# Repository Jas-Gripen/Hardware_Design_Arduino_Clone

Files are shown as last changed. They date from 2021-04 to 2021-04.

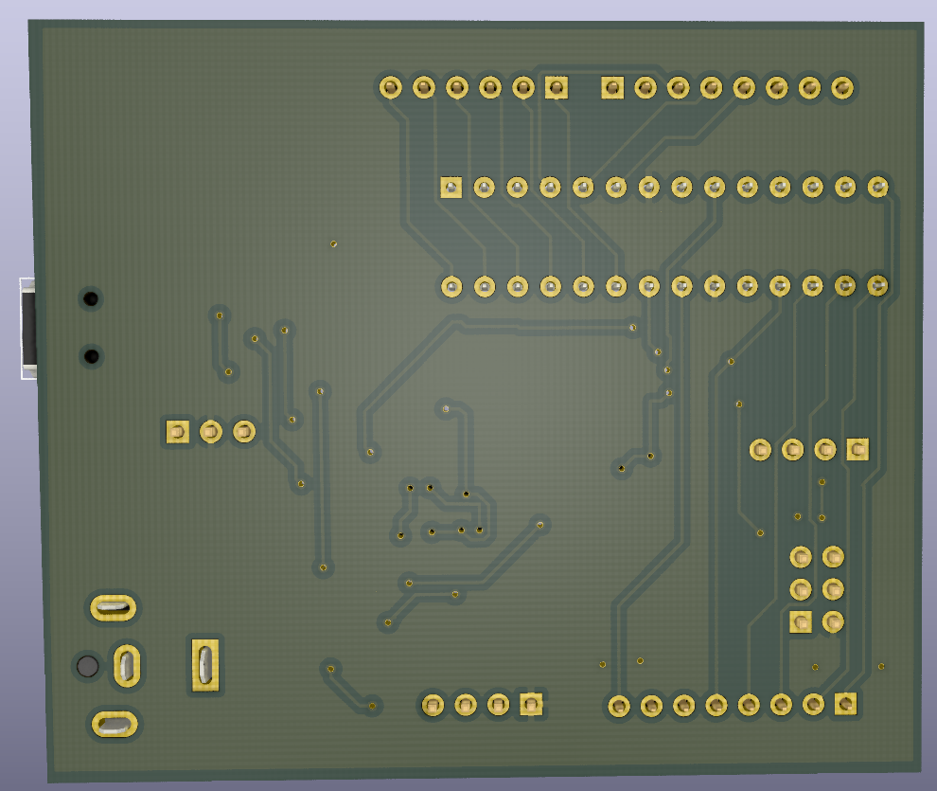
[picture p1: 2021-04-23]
Pictures/3D_image_of_board_bottom_view.png

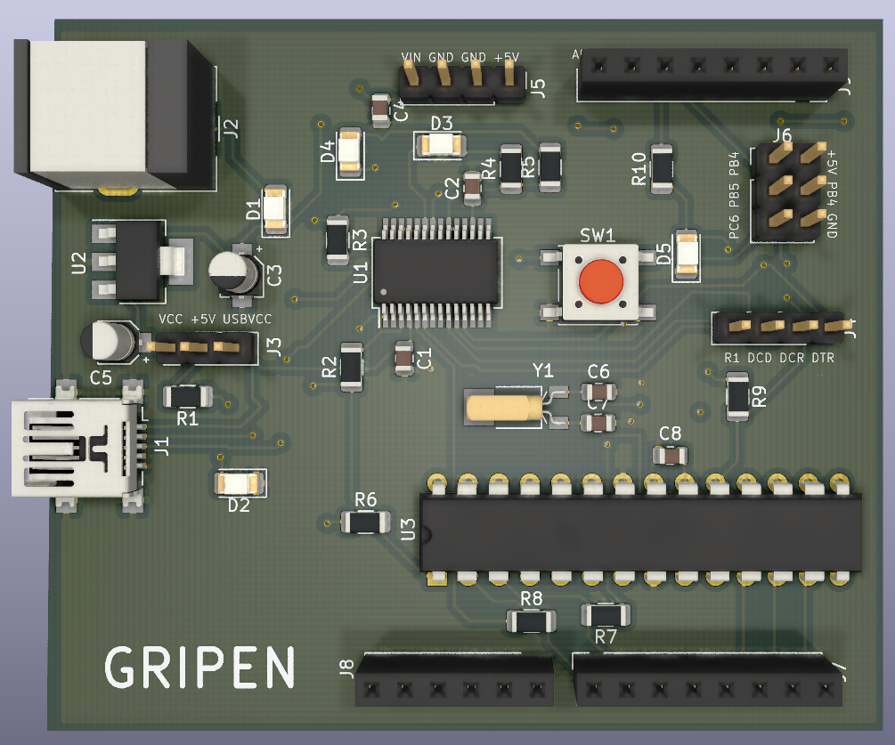
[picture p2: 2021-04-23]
Pictures/3D_image_of_board_top_view.png

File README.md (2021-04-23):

# Hardware_Design_Arduino_Clone
I made schematics for an Arduino Clone in KiCad.
There is a description of why I chosed to design the board like I did in the PCB_Report.pdf file.

The original schematic (only Eeschema type) are avalible here: https://www.arduino.cc/en/uploads/Main/arduino_NG_schematic.png
The placement of the components as well as the version of them are of my own choosing. The same goas for the PCB-traces and vias.

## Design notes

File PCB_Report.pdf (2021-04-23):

## PCB Report

Abstract

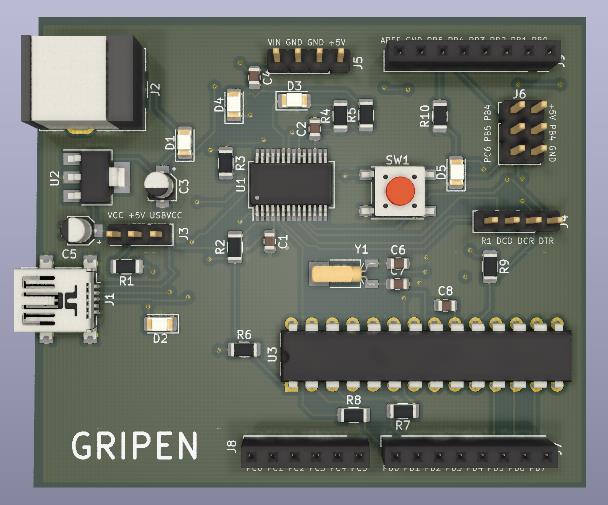
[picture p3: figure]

3D visualization of a pcb-design(Arduino clone), Pcbnew, KiCad, Daniel Gripenstedt

This document contains a description of a PCB design. The report should clarify why the circuit board looks the way it does and the thoughts behind the different design choices. There are also pictures of various drawings and 3D visualization of the circuit board.

### Overview

The circuit board is an Arduino clone (Arduino Nuova Generazione (NG) v4.0) which has an 8-bit MCU (ATmega8-16PU [1] and an FT232RL (USB-UART interface) [2]. Program code is sent over with a USB mini-B cable, which can also act as a power supply. There are several LEDs and a reset button. A crystal of 16MHz is placed on the card. All drawings are created with KiCad [3].

### Components

Most components are of type SMD as these are cheaper than THT. Contact pins and power supply are of type THT. In total, there are 37 components where the smallest are 0805. Smaller components were not considered necessary as there was sufficient space on the card. All components are located on the top of the card.

### Microcontroller

The microcontroller used is an ATmega8-16PU. This MCU has 8Kbytes of On-Chip In-System Reprogrammable Flash memory. Program code is sent over with a USB mini-B cable using the MCU's Boot Loader-Support [1].

### Power and power supply

The MCU requires 4.5V – 5.5V voltage [1]. Two polarized capacitors with 100uF have been placed by the cards power supply as they may have a higher capacitance at a lower price than those that are not polarized.

Voltage can be supplied directly with 5V from USB mini-B or via a voltage divider and the card's "power jack" but it is also possible to connect an external power source via the VIN stick connected before the voltage divider. Several decoupling capacitors have been used to protect the circuits from current spikes.

Power options:

1. USB mini-B cable connected to, for example, a computer.
2. Power Jack with, for example, an AC to DC converter.
3. VIN stick with, for example, a 9V battery.

### PCB Layout

This design is of a two-layer card with a ground plane and a voltage plane. The crystal Y1 is located near the MCU and the loading capacitance have been placed close to the crystal. This is good because it is a sensitive circuit. The load capacitances are positioned so that their fields are counterproductive and the signals from the crystal travels close to each other so that the magnetic fields cancel each other out. No other wires have been pulled parallel or above which may interfere. The ground signal from the crystal to the MCU is short and close to the other two signals, which gives a small loop area. The ground plane got disconnected by the crystal but was solved by connecting a bridge between the connected and disconnected ground planes.

Decoupling capacitors are located near the circuits they decouple to minimize impedance and maximize decoupling efficiency.

Wires and ground/voltage planes are located a bit in from the edge of the card to prevent interference (the card may otherwise act as a patch antenna).

The circuit is partitioned so that power/voltage supply is placed on one part of the card, the MCU with resistors, crystal and capacitors on another and the FT232RL with resistors, diodes and capacitors on another part of the card.

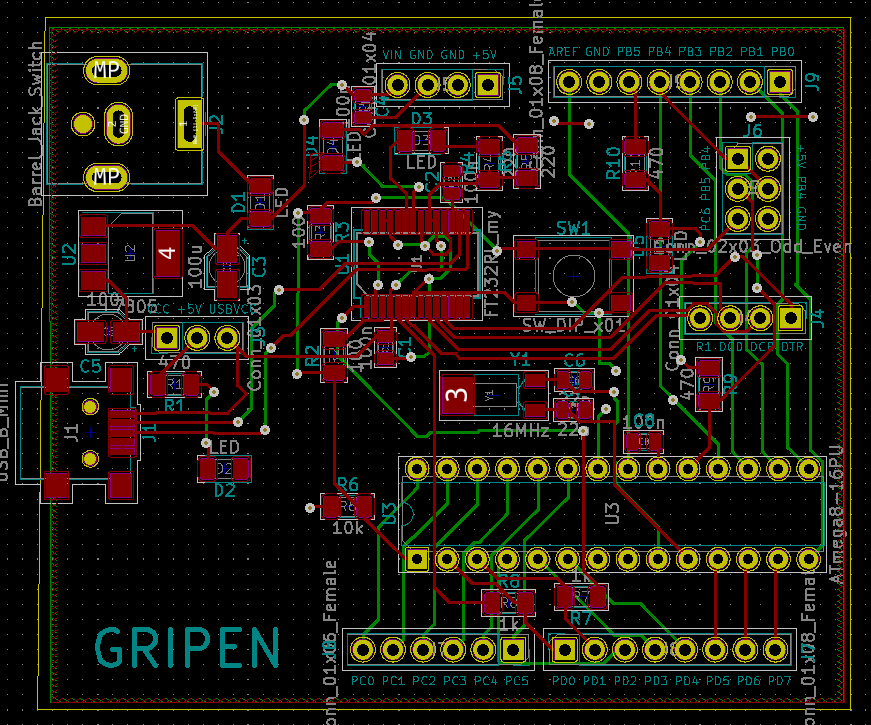
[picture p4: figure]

Front of the circuitboard, Pcbnew, KiCad, Daniel Gripenstedt

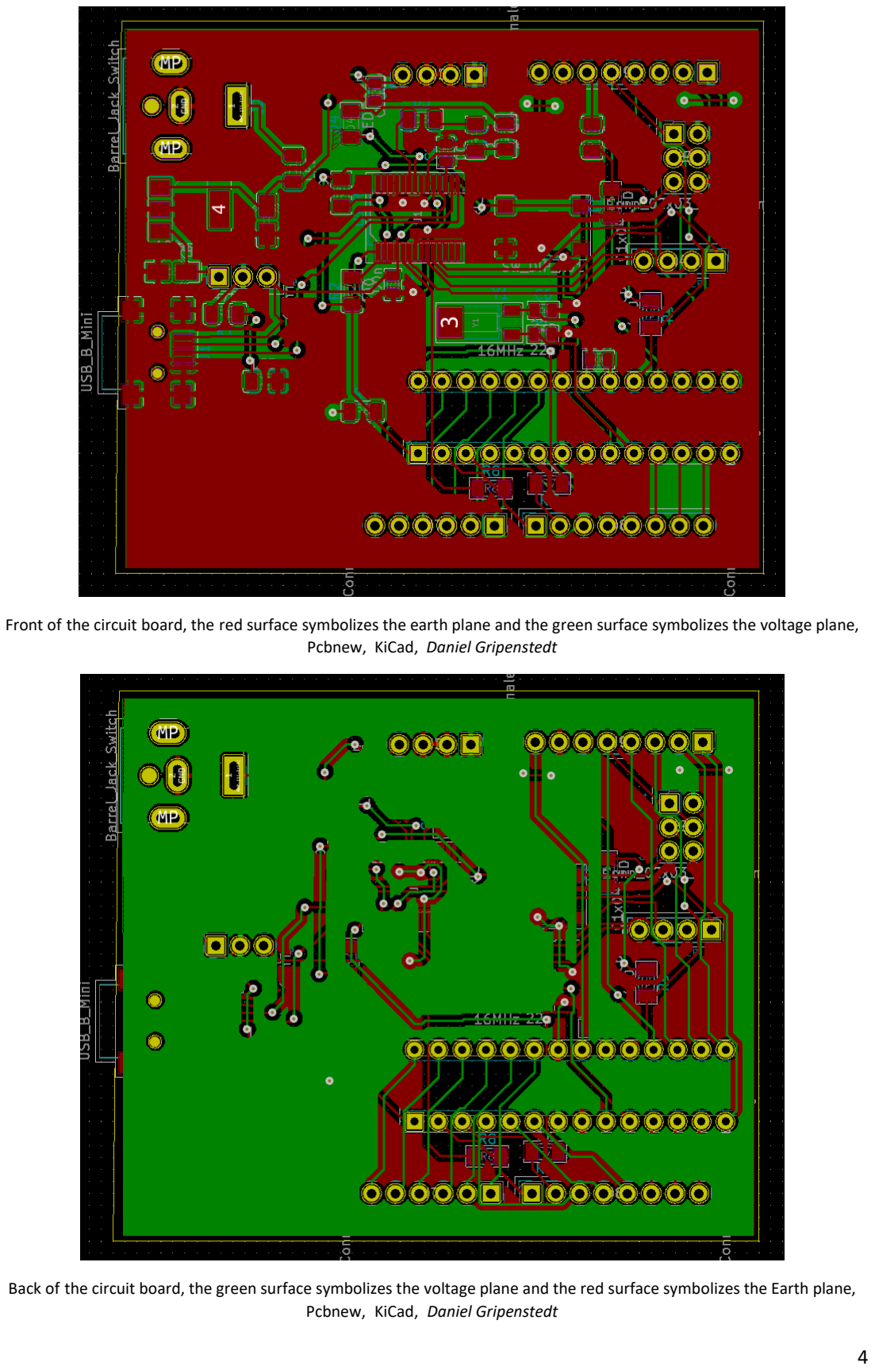
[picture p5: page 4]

Front of the circuit board, the red surface symbolizes the earth plane and the green surface symbolizes the voltage plane, Pcbnew, KiCad, Daniel Gripenstedt

Back of the circuit board, the green surface symbolizes the voltage plane and the red surface symbolizes the Earth plane, Pcbnew, KiCad, Daniel Gripenstedt

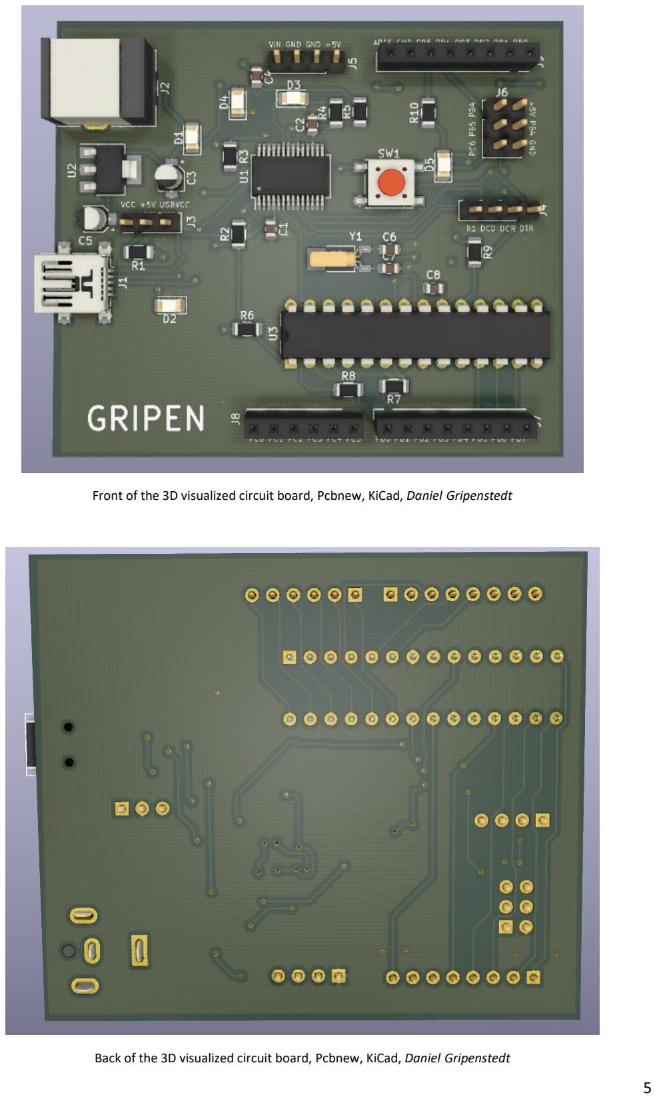
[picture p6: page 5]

Front of the 3D visualized circuit board, Pcbnew, KiCad, Daniel Gripenstedt

Back of the 3D visualized circuit board, Pcbnew, KiCad, Daniel Gripenstedt

### Drawing

The first image is on the entire drawing, the three lower slides are parts of the drawing but on a larger scale.

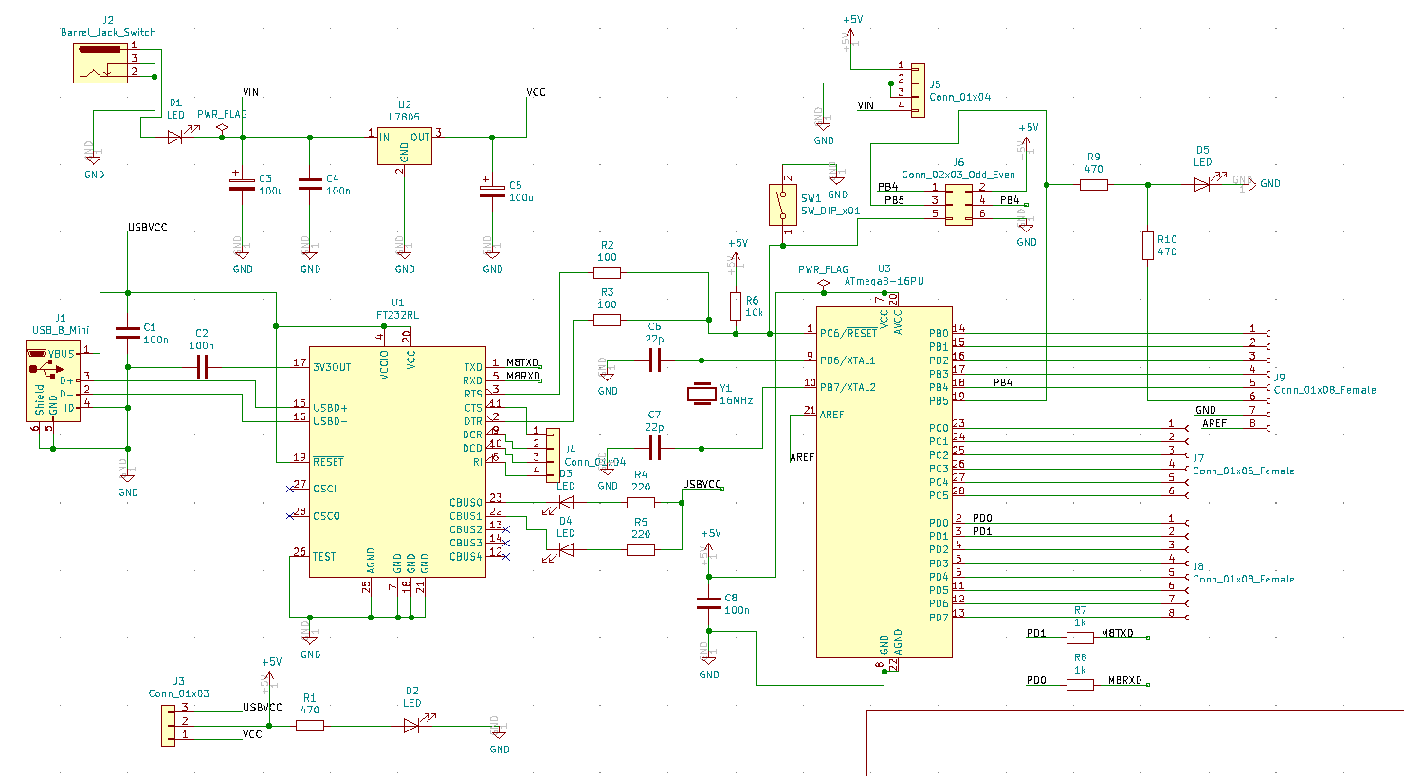
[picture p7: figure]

Drawing in Easchema, KiCad, Daniel Gripenstedt

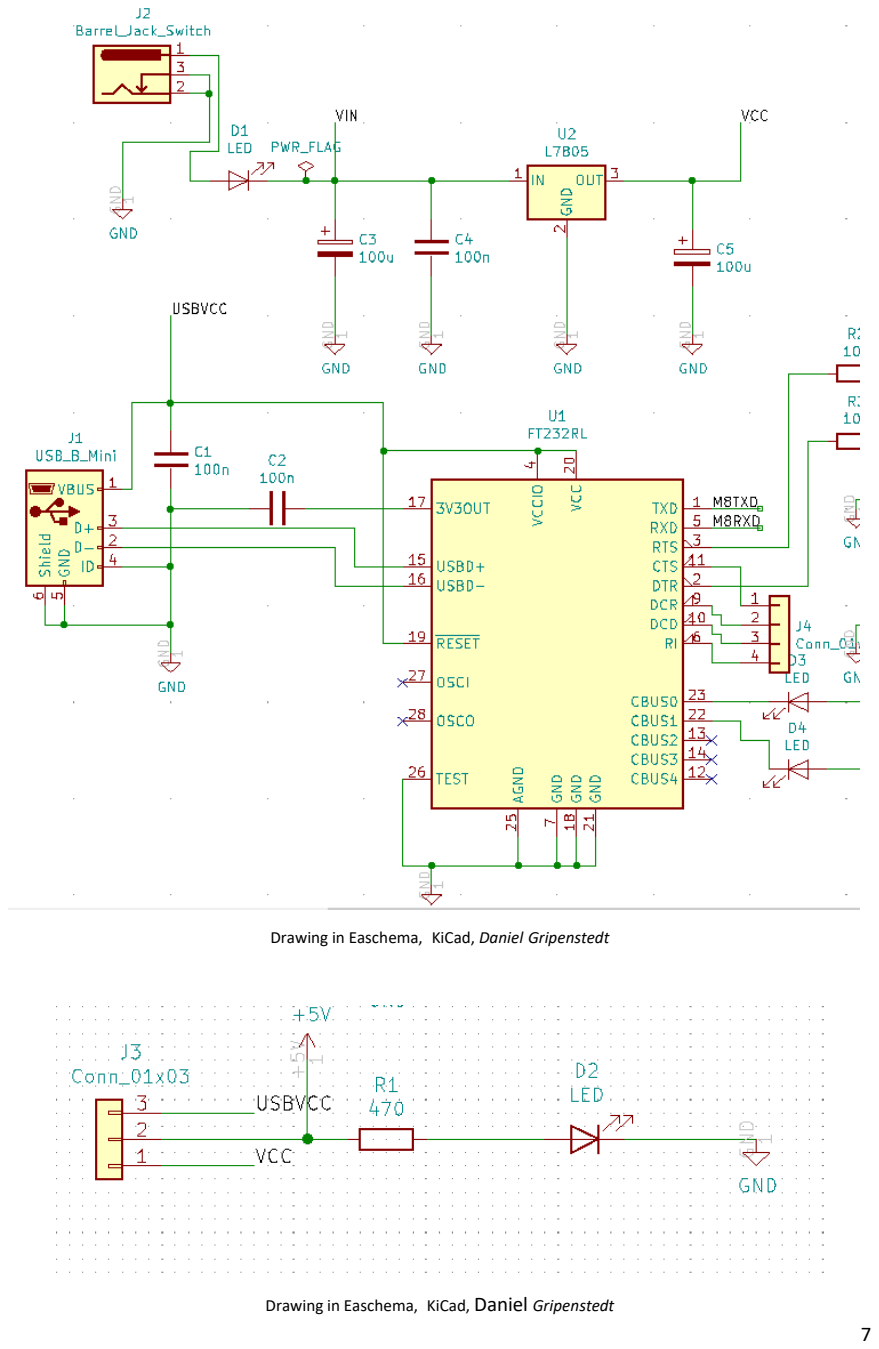
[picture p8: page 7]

Drawing in Easchema, KiCad, Daniel Gripenstedt

Drawing in Easchema, KiCad, Daniel Gripenstedt

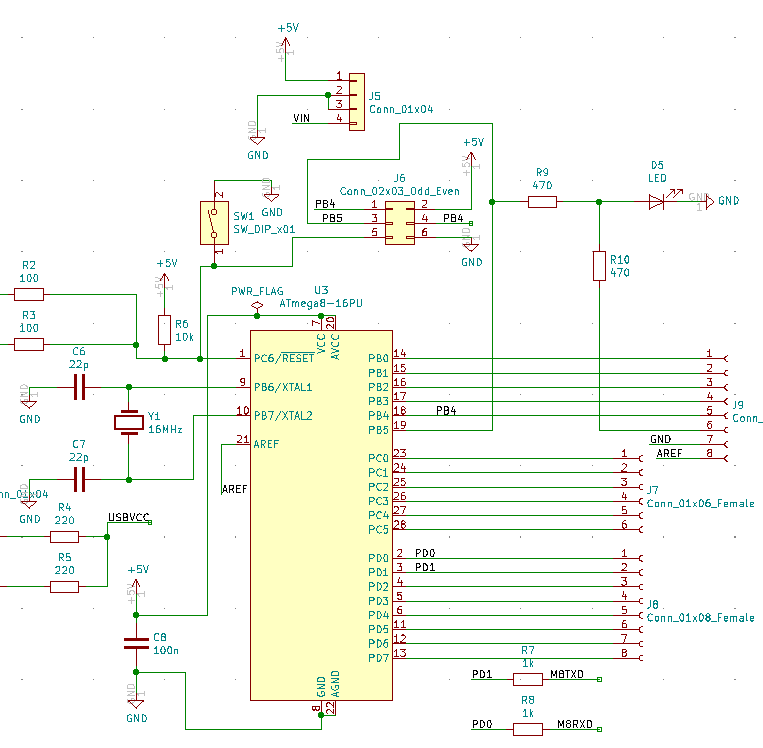
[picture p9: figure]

Drawing in Easchema, KiCad, Daniel Gripenstedt

### Bom List

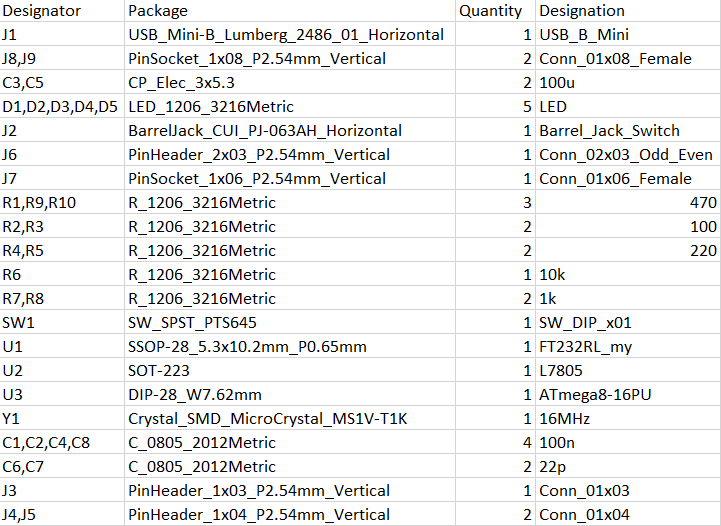
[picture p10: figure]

BOM list generated by Pcbnew, KiCad, Daniel Gripenstedt

### References

[1] (2020), ATmega8/L datasheet - ATMEGA8-16PU-Microchip datasheet-14702621.pdf, Available: https://datasheet.octopart.com/ATMEGA8-16PU-Microchip-datasheet-14702621.pdf
[2] (2020), FT232R - DS_FT232R.pdf, Available: https://www.ftdichip.com/Support/Documents/DataSheets/ICs/DS_FT232R.pdf
[3] (2020), KiCad EDA, A Cross Platform and Open Source Electronics Design Automation Suite, Available: https://kicad-pcb.org/

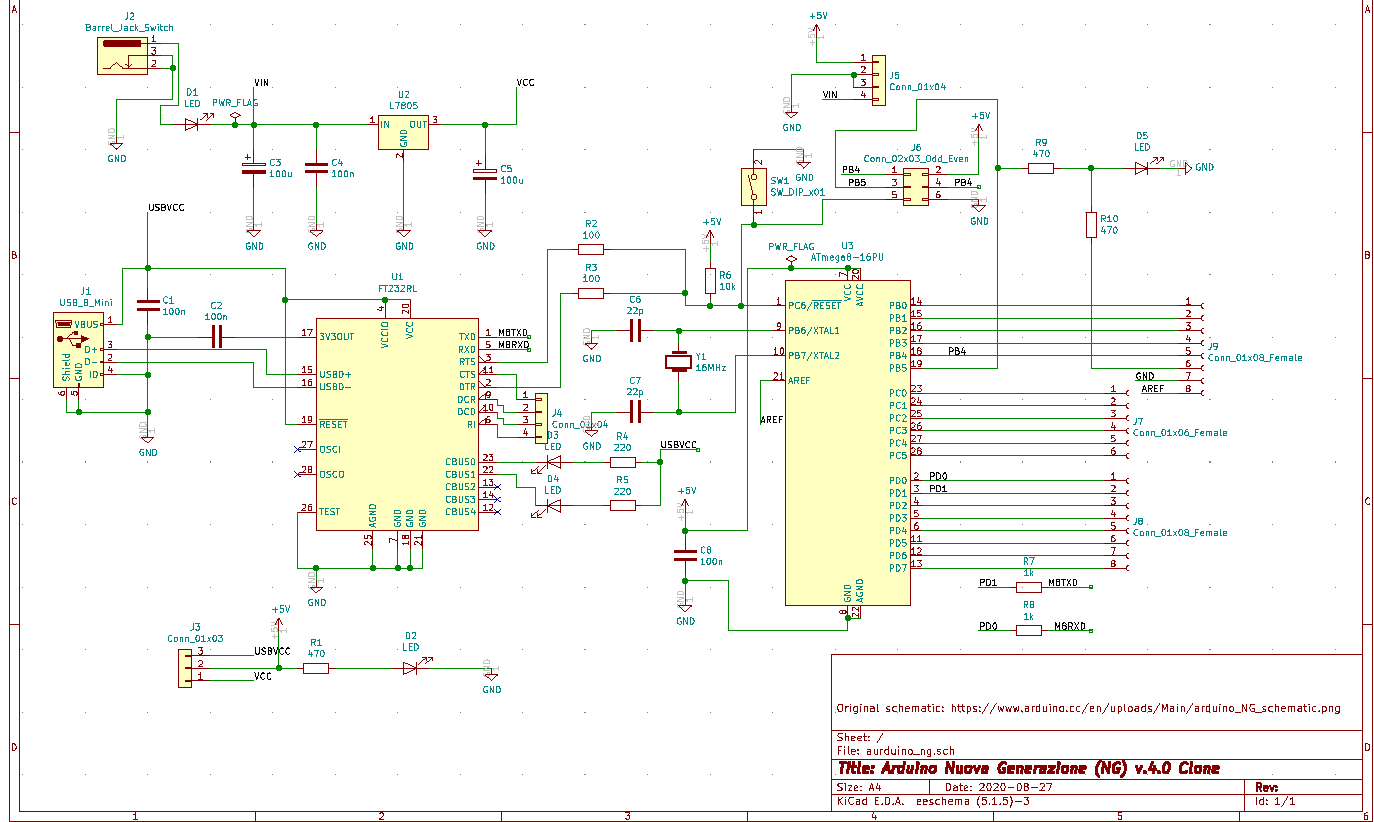
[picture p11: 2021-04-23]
Pictures/Eeschema.png

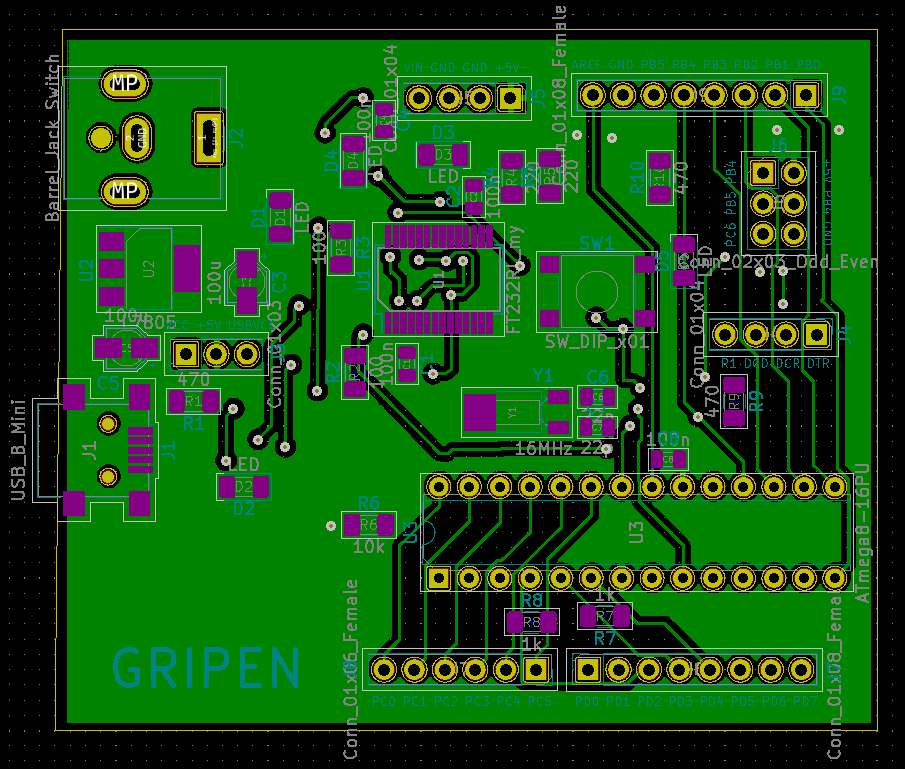
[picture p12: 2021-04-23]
Pictures/Pcbnew_bottom_plane.png

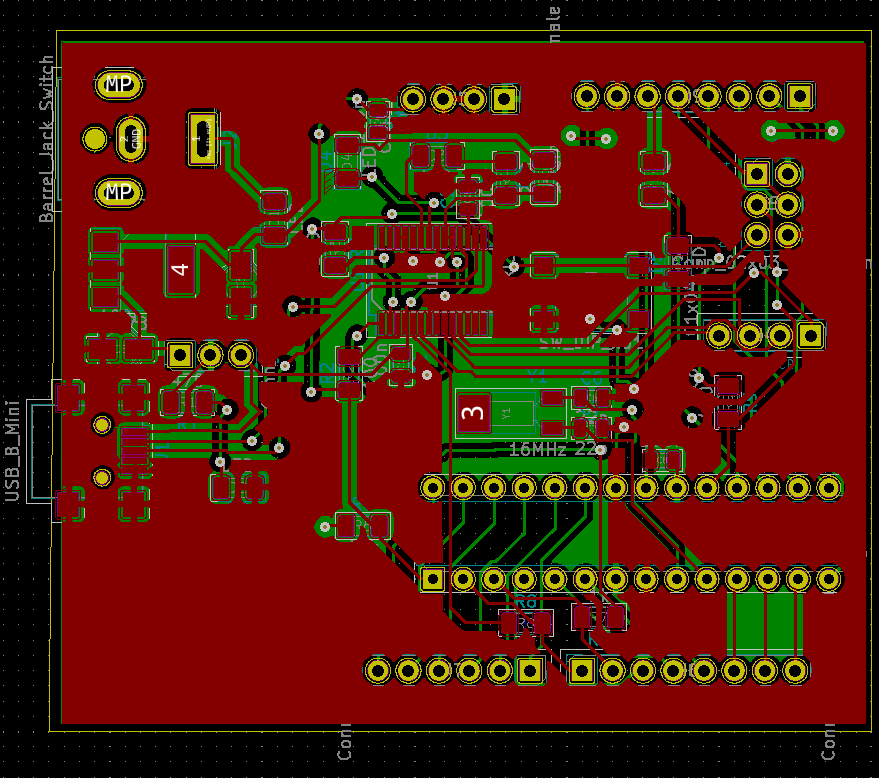
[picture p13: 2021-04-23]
Pictures/Pcbnew_top_plane.png

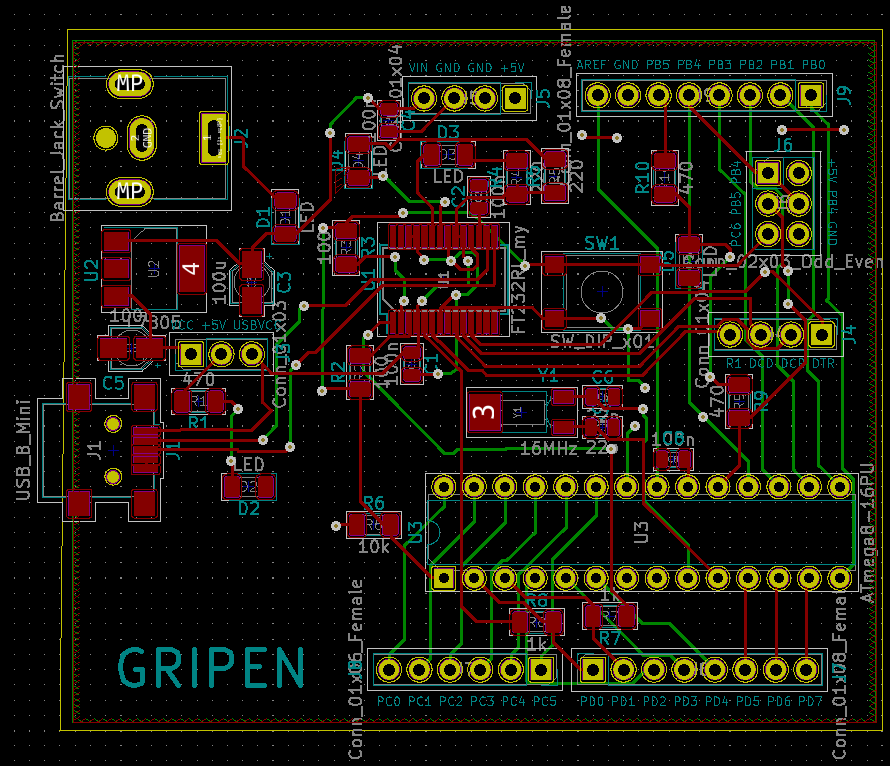
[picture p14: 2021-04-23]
Pictures/Pcbnew.png

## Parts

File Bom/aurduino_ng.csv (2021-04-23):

Id | Designator | Package | Quantity | Designation | Supplier and ref
1 | J1 | USB_Mini-B_Lumberg_2486_01_Horizontal | 1 | USB_B_Mini
2 | J8,J9 | PinSocket_1x08_P2.54mm_Vertical | 2 | Conn_01x08_Female
3 | C3,C5 | CP_Elec_3x5.3 | 2 | 100u
4 | D1,D2,D3,D4,D5 | LED_1206_3216Metric | 5 | LED
5 | J2 | BarrelJack_CUI_PJ-063AH_Horizontal | 1 | Barrel_Jack_Switch
6 | J6 | PinHeader_2x03_P2.54mm_Vertical | 1 | Conn_02x03_Odd_Even
7 | J7 | PinSocket_1x06_P2.54mm_Vertical | 1 | Conn_01x06_Female
8 | R1,R9,R10 | R_1206_3216Metric | 3 | 470
9 | R2,R3 | R_1206_3216Metric | 2 | 100
10 | R4,R5 | R_1206_3216Metric | 2 | 220
11 | R6 | R_1206_3216Metric | 1 | 10k
12 | R7,R8 | R_1206_3216Metric | 2 | 1k
13 | SW1 | SW_SPST_PTS645 | 1 | SW_DIP_x01
14 | U1 | SSOP-28_5.3x10.2mm_P0.65mm | 1 | FT232RL_my
15 | U2 | SOT-223 | 1 | L7805
16 | U3 | DIP-28_W7.62mm | 1 | ATmega8-16PU
17 | Y1 | Crystal_SMD_MicroCrystal_MS1V-T1K | 1 | 16MHz
18 | C1,C2,C4,C8 | C_0805_2012Metric | 4 | 100n
19 | C6,C7 | C_0805_2012Metric | 2 | 22p
20 | J3 | PinHeader_1x03_P2.54mm_Vertical | 1 | Conn_01x03
21 | J4,J5 | PinHeader_1x04_P2.54mm_Vertical | 2 | Conn_01x04

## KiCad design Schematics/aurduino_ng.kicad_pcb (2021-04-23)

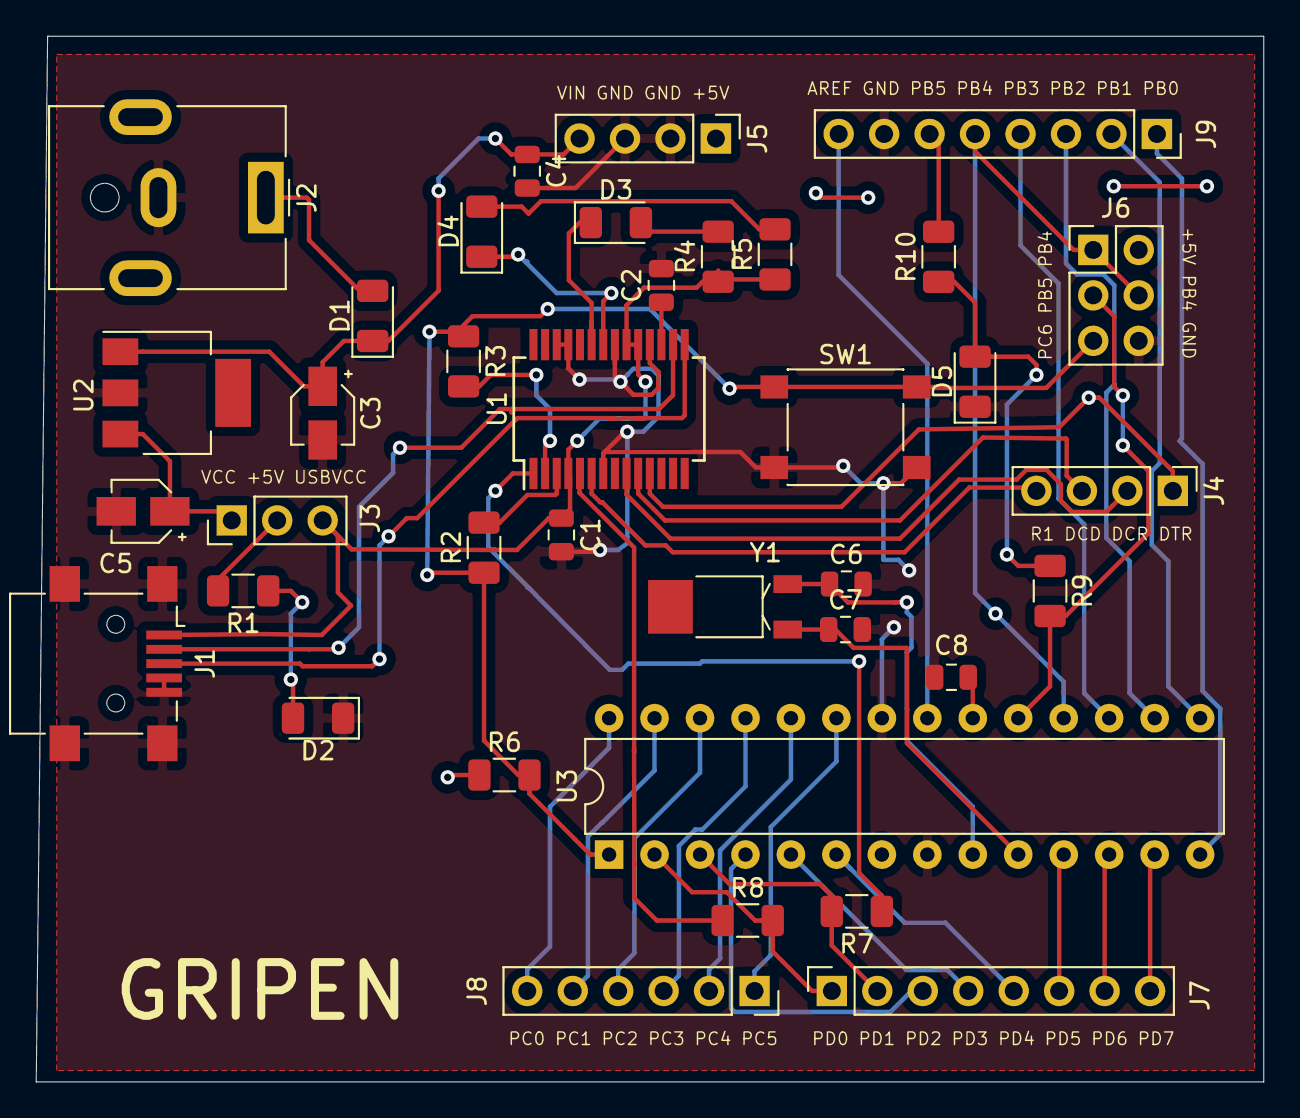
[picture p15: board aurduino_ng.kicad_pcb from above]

Board: 2 copper layers, 68.6 x 58.4 mm, 37 parts (0 on the bottom side), 48 nets.

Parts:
C1, C2, C4, C8: 100n; C_0805_2012Metric
C3, C5: 100u; CP_Elec_3x5.3
C6, C7: 22p; C_0805_2012Metric
D1, D2, D3, D4, D5: LED; LED_1206_3216Metric
J1: USB_B_Mini; USB_Mini-B_Lumberg_2486_01_Horizontal
J2: Barrel_Jack_Switch; BarrelJack_CUI_PJ-063AH_Horizontal
J3: Conn_01x03; PinHeader_1x03_P2.54mm_Vertical
J4, J5: Conn_01x04; PinHeader_1x04_P2.54mm_Vertical
J6: Conn_02x03_Odd_Even; PinHeader_2x03_P2.54mm_Vertical
J7: Conn_01x06_Female; PinSocket_1x06_P2.54mm_Vertical
J8, J9: Conn_01x08_Female; PinSocket_1x08_P2.54mm_Vertical
R1, R9, R10: 470; R_1206_3216Metric
R2, R3: 100; R_1206_3216Metric
R4, R5: 220; R_1206_3216Metric
R6: 10k; R_1206_3216Metric
R7, R8: 1k; R_1206_3216Metric
SW1: SW_DIP_x01; SW_SPST_PTS645
U1: FT232RL_my; SSOP-28_5.3x10.2mm_P0.65mm
U2: L7805; SOT-223
U3: ATmega8-16PU; DIP-28_W7.62mm
Y1: 16MHz; Crystal_SMD_MicroCrystal_MS1V-T1K

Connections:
+5V: C8.1, J3.2, J5.1, J6.2, R1.2, R6.1, U3.7, U3.20
/AREF: J9.8, U3.21
/M8RXD: R8.1, U1.5
/M8TXD: R7.1, U1.1
/PB4: J6.1, J6.4, J9.5, U3.18
/PB5: J6.3, R9.2, U3.19
/PD0: J8.1, R8.2, U3.2
/PD1: J8.2, R7.2, U3.3
/USBVCC: C1.1, J1.1, J3.3, R4.1, R5.1, U1.4, U1.19, U1.20
/VCC: C5.1, J3.1, U2.3
/VIN: C3.1, C4.1, D1.1, J5.4, U2.1
GND: C1.2, C2.2, C3.2, C4.2, C5.2, C6.2, C7.2, C8.2, D2.1, D5.1, J1.4, J1.5, J1.6, J2.2, J5.2, J5.3, J6.6, J9.7, SW1.2, U1.7, U1.18, U1.21, U1.25, U1.26, U2.2, U3.8, U3.22
unnamed: C2.1, U1.17
unnamed: C6.1, U3.9, Y1.1
unnamed: C7.1, U3.10, Y1.2
unnamed: D1.2, J2.1
unnamed: D2.2, R1.1
unnamed: D3.1, U1.23
unnamed: D3.2, R4.2
unnamed: D4.1, U1.22
unnamed: D4.2, R5.2
unnamed: D5.2, R9.1, R10.1
unnamed: J1.2, U1.16
unnamed: J1.3, U1.15
unnamed: J4.1, U1.11
unnamed: J4.2, U1.9
unnamed: J4.3, U1.10
unnamed: J4.4, U1.6
unnamed: J6.5, R2.1, R3.1, R6.2, SW1.1, U3.1
unnamed: J7.1, U3.23
unnamed: J7.2, U3.24
unnamed: J7.3, U3.25
unnamed: J7.4, U3.26
unnamed: J7.5, U3.27
unnamed: J7.6, U3.28
unnamed: J8.3, U3.4
unnamed: J8.4, U3.5
unnamed: J8.5, U3.6
unnamed: J8.6, U3.11
unnamed: J8.7, U3.12
unnamed: J8.8, U3.13
unnamed: J9.1, U3.14
unnamed: J9.2, U3.15
unnamed: J9.3, U3.16
unnamed: J9.4, U3.17
unnamed: J9.6, R10.2
unnamed: R2.2, U1.3
unnamed: R3.2, U1.2

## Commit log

2021-04-23 Pushed all the files
    [aurduino_ng-B_Cu.gbr, aurduino_ng-B_Mask.gbr, aurduino_ng-Edge_Cuts.gbr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]
2021-04-23 Pushed png files, schematics and 3D board
2021-04-23 Moved files into folders
    [aurduino_ng.kicad_pcb, aurduino_ng.sch]
2021-04-23 Added the PCB Report
